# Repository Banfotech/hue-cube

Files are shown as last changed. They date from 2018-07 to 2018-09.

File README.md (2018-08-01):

# Introduction 

The HueCube is a small colorful, programmable cube measuring 46x46x46mm.
You can play around with the example code using the [Arduino IDE](https://www.arduino.cc/), and change it's behavior.
By reading data from the embedded sensors, you can let the colors change by temperature, height, angle, tapping, tilting, dropping or humidity. See the following videos for a few examples:

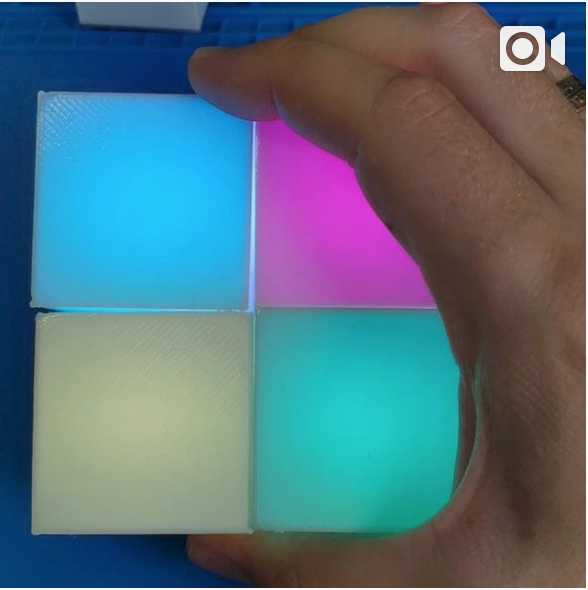
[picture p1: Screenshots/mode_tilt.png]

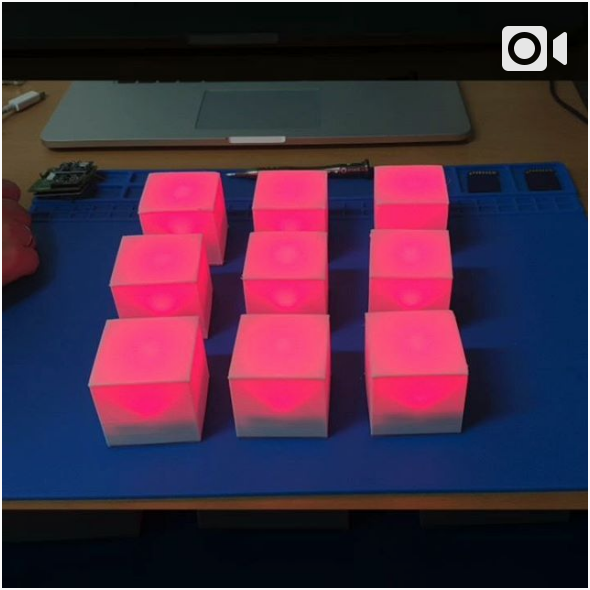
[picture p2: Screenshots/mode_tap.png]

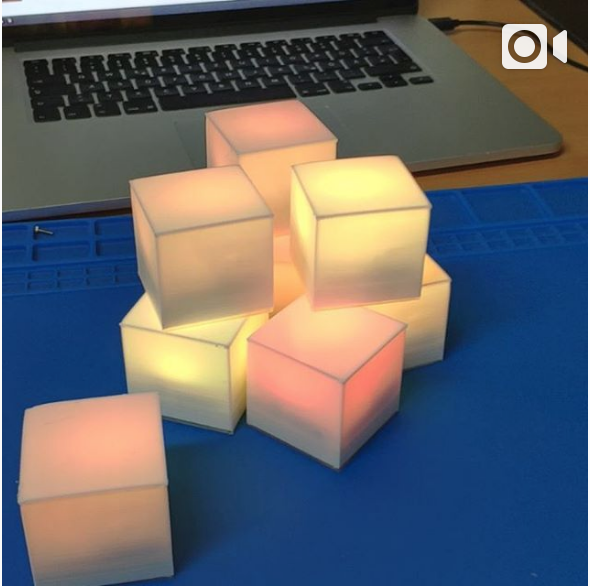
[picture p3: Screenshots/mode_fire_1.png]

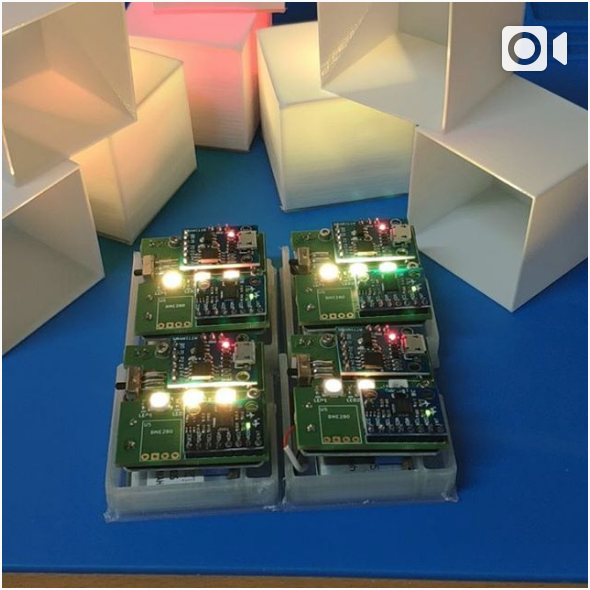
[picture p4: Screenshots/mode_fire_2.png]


## What do you need?

### Soldering
To assemble the board you need to be able to solder SMD components (0603) and a few pins. I am using [this](https://www.aliexpress.com/item/Hot-Sale-220V-110V-60W-Adjustable-Temperature-Electric-Soldering-Iron-Welding-Solder-Station-Heat-Pencil-With/32434361333.html) and [this](https://www.aliexpress.com/item/Free-Shipping-0-3mm-0-4mm-0-5-mm0-6mm-Tin-Lead-Rosin-Core-Solder-Wire/32335236726.html).

### Software
- [Blender3D](https://www.blender.org/), to design the 3d printed case:
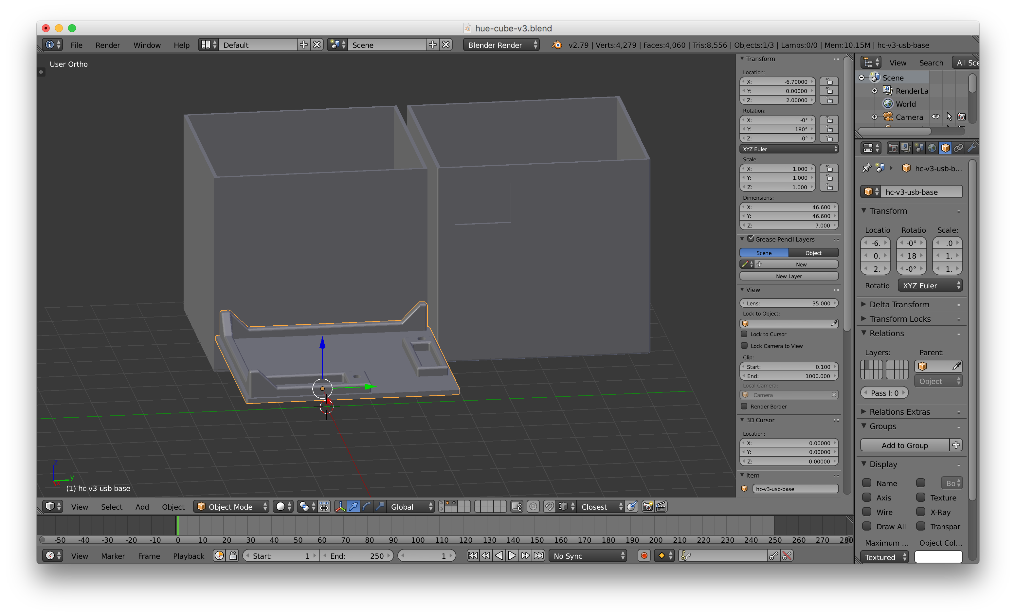
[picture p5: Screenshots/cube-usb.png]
    * USB Powered: <br/>
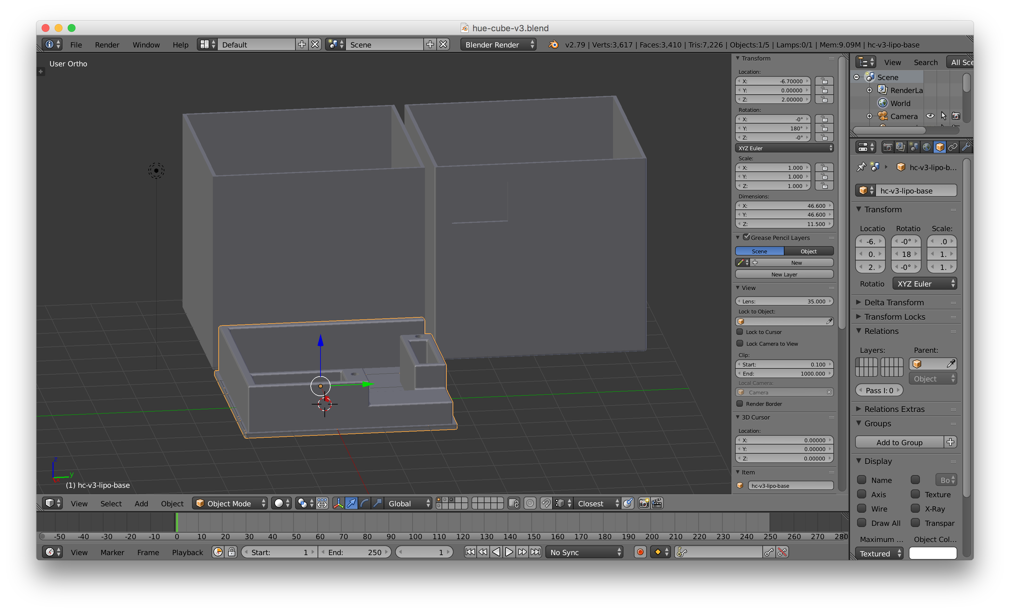
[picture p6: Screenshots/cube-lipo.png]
    * LiPo Powered:<br/>
- [KiCad](http://kicad-pcb.org/), to design the PCB
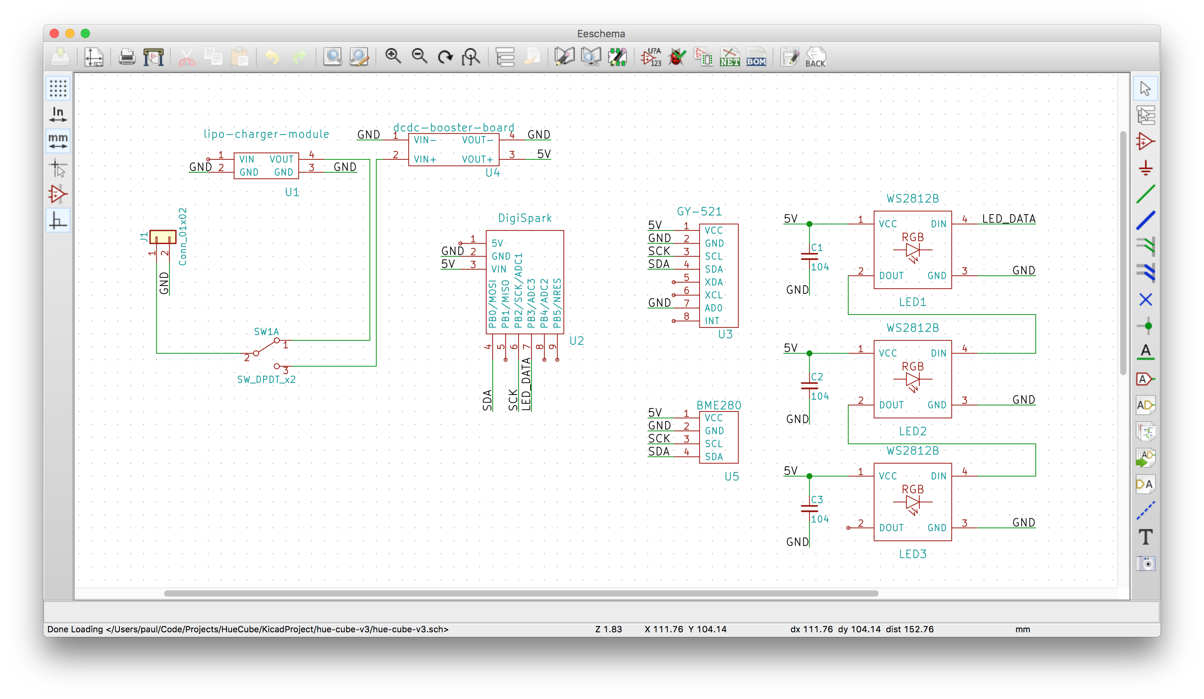
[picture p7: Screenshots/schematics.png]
    * Schematics: <br/>
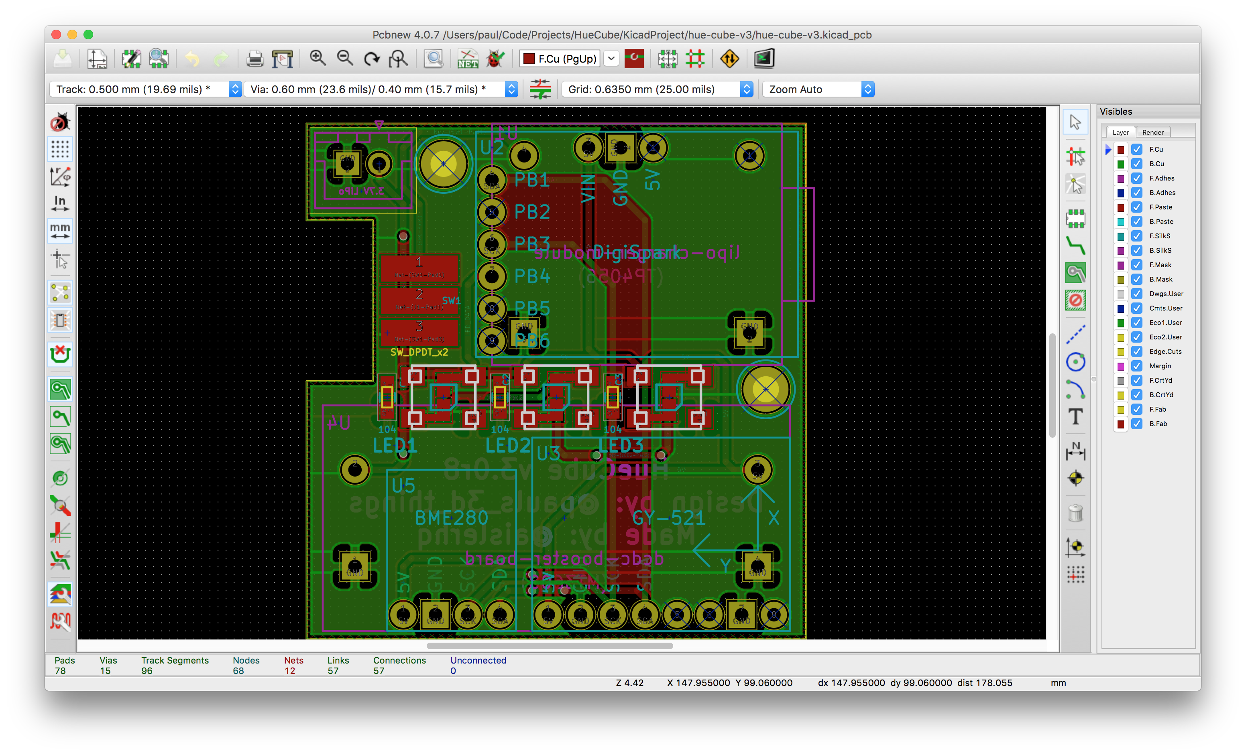
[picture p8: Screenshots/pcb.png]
    * Circuit Board: <br/>
- [Arduino IDE](https://www.arduino.cc/), to write the code and flash the device
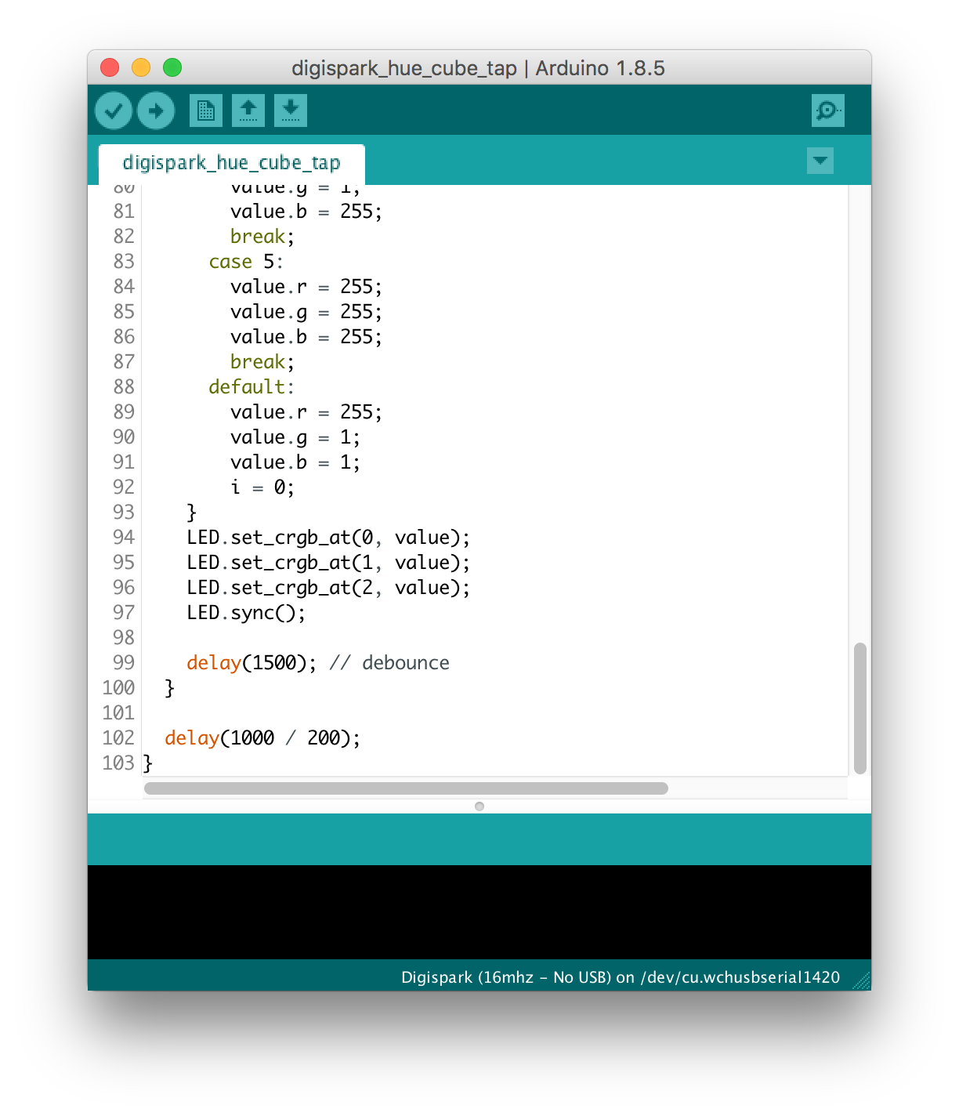
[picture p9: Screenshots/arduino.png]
   * <br/>
   * The [light_ws2812](https://github.com/cpldcpu/light_ws2812) library to control the LEDs. Download the .zip from the `/light_ws2812_Arduino/` folder and place it into `Arduino/libraries/`. I chose this library, due to the small flash size of the attiny85.

### Hardware
The HueCube is made of small, electronic modules that are soldered onto a PCB. You can order the PCB directly from [AISLER](https://aisler.net/p/VAADXKWB), or use the [KiCad](http://kicad-pcb.org/) project files form this repository to modify it.
Currently, there are two design variant.

- USB Powered
    * 3D printed parts: 1x `BlenderModel/hc-v3-usb-base.stl` and  1x `BlenderModel/hc-v3-usb-cube.stl`
    * [1x ATTiny / DigiSpark](https://www.aliexpress.com/item/Attiny85-Digispark-Kickstarter-Development-Board-Module-For-Arduino-Built-in-USB-500ma-5V-Regulator-8k-Flash/32279051124.html)
    * [1x MPU-6050](https://www.aliexpress.com/item/MPU-6050-3-Axis-gyroscope-acce-lerometer-module-3V-5V-compatible-For-Arduino/2035920870.html)
    * [1x ON/OFF Switch](https://www.aliexpress.com/item/Promotion-50-Pcs-SS12D00G3-2-Position-SPDT-1P2T-3-Pin-PCB-Panel-Mini-Vertical-Slide-Switch/32649542037.html) (I know, not the ideal switch, but I had those lying around, so I will be using them)
    * [3x WS2812B](https://www.aliexpress.com/item/100PCS-New-Version-WS2812B-5050-RGB-SMD-WS2811-IC-WS2812-For-Strip-Screen-etc/32776703442.html) you can use them for all sorts of projects ;)
    * [3x 0603 100nF Capacitor](https://www.aliexpress.com/item/MCIGICM-100pcs-0603-smd-capacitor-ceramic-22pf-100nf-1uf-2-2uf-4-7uf-10uf-capacitors-kit/32841971485.html) (or you could search for a kit with multiple values)
- LiPo Powered
    * 3D printer files: 1x `BlenderModel/hc-v3-lipo-base.stl` and 1x `BlenderModel/hc-v3-lipo-cube.stl`
    * [1x TP4056 LiPo Charger](https://www.aliexpress.com/item/5Pcs-Lot-TP4056-Micro-USB-5V-1A-18650-Lithium-Battery-Charger-Board-With-Led-Indicator-Over/32675099957.html) **⚠️make sure to replace the PROG resistor⚠️**. The resistor value depends on your LiPo size. When using a 400mA battery, use [1x 10k Ohm 0603](https://www.aliexpress.com/item/300pcs-0603-SMD-Resistor-1-6-8K-7-5K-8-2K-9-1K-10K-ohm/32308220603.html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), this will give you around ~100mA charging current. (or you could search for a kit with multiple values)
    * [1x MT3608 DC-DC Step Up Converter](https://www.aliexpress.com/item/5pcs-MT3608-DC-DC-Step-Up-Power-Apply-Module-Booster-Power-Module-MAX-output-28V-2A/32517710689.html) **⚠️set this to 5V output before soldering⚠️**

## How to Build?

### Soldering

#### Manually soldering the LEDs
First, solder the WS2812B to the PCB, note the corner with the triangle is GND, so this needs to be aligned to the bottom right pad. See the video for detais:

*Video:*

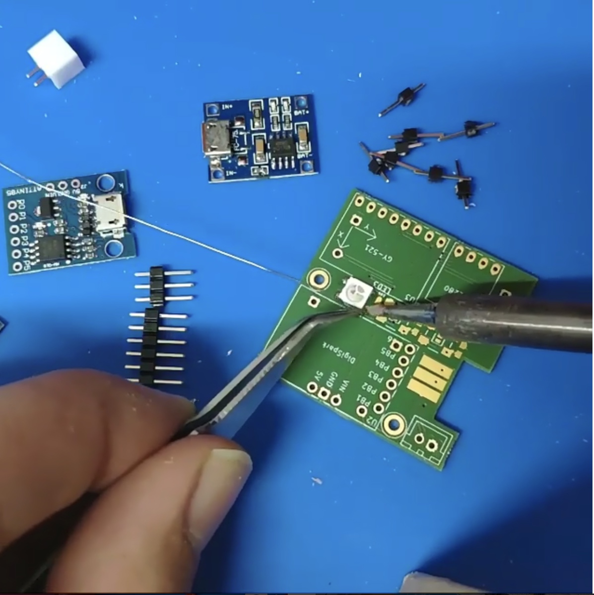
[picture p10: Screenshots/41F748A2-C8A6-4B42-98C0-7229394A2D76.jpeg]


#### SMD soldering the LEDs
If you have a hot airstation and liquid solder, it is a lot easier to solder the SMD components:

*Video:*

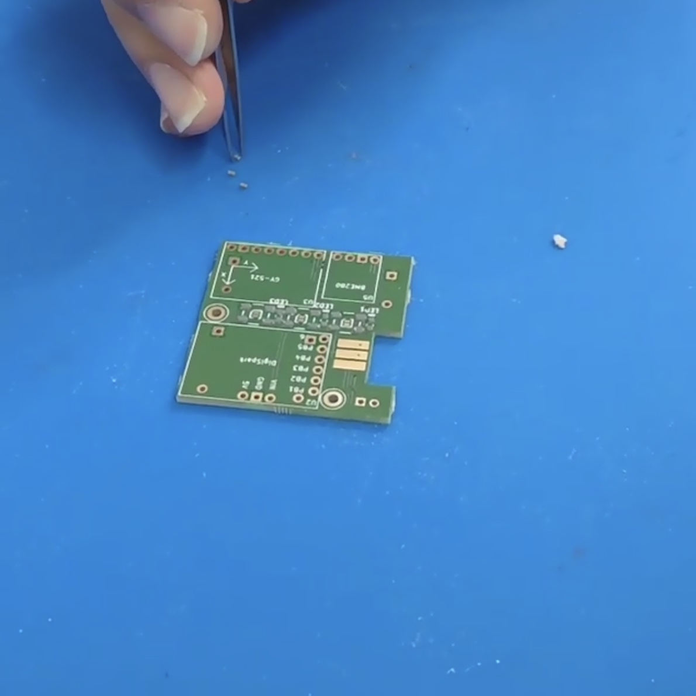
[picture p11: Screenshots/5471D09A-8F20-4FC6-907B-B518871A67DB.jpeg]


#### Pins
After the LEDs and capacitors, you will need to solder the pins. 
**Important:** You need to know in advance if you want to build the LiPo version or not, otherwise you will not be able to add the respective pins for the DCDC booster and the LiPo charger module.

*Video:*

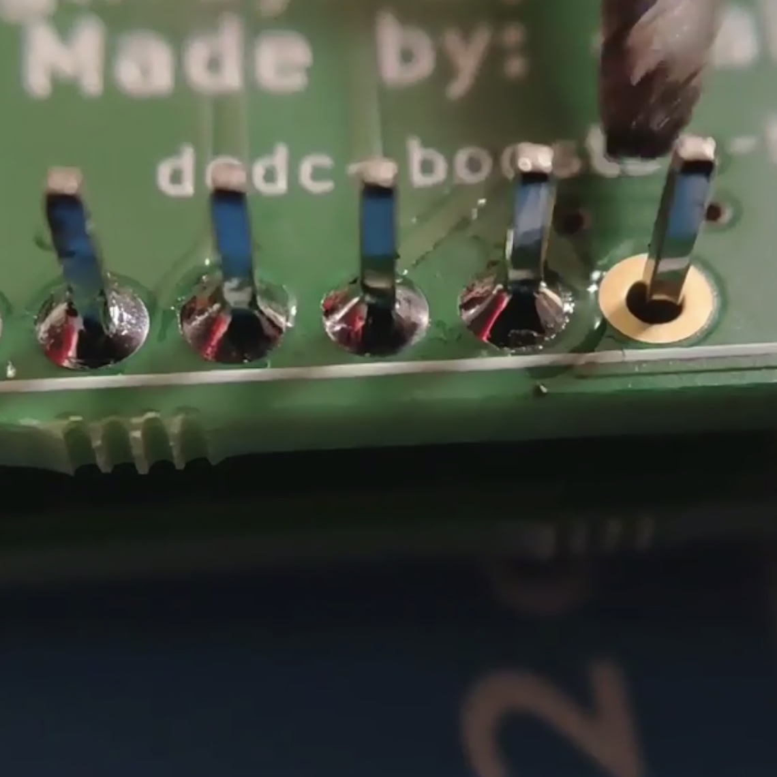
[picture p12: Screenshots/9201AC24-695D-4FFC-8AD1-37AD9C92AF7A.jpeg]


#### Sensor + DigiSpark (USB Version)
The USB version only requires soldering the top parts

*Video:*

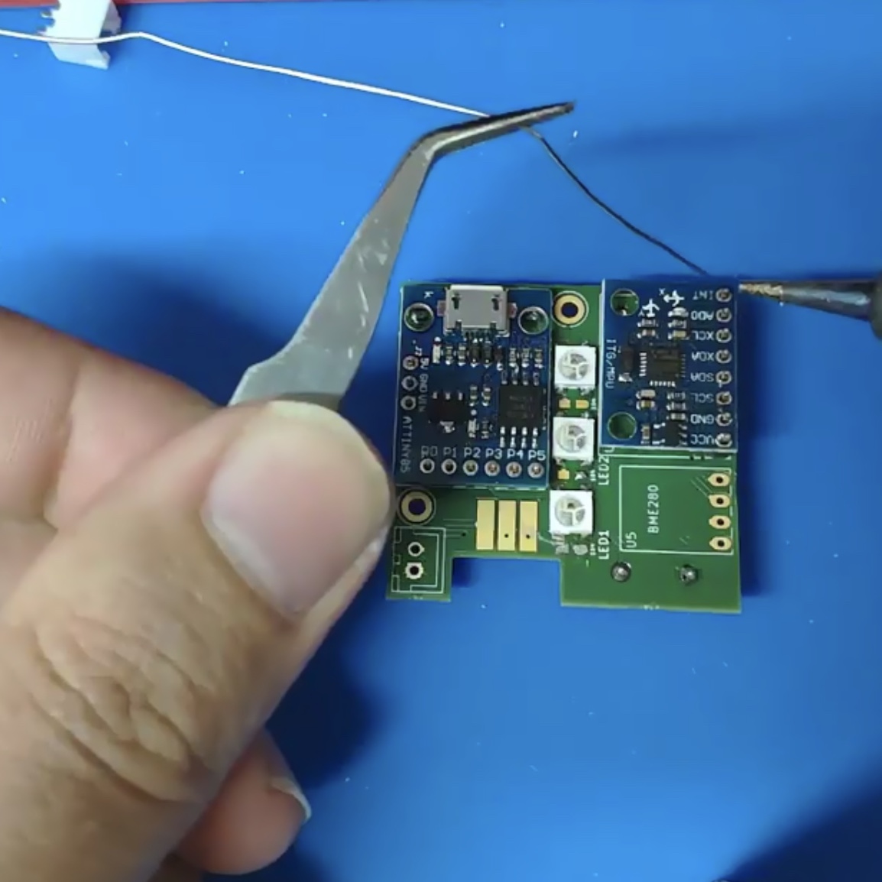
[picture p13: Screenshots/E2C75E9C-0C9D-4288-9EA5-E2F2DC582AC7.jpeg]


#### DCDC Booster + LiPo Charger
Note, make sure you have the pins in place. Set the DCDC booster to 5V **before soldering** and **replace the PROG resistor** with a 10k resistor to make sure you only have small charging current of about 120mA.

*Video:*

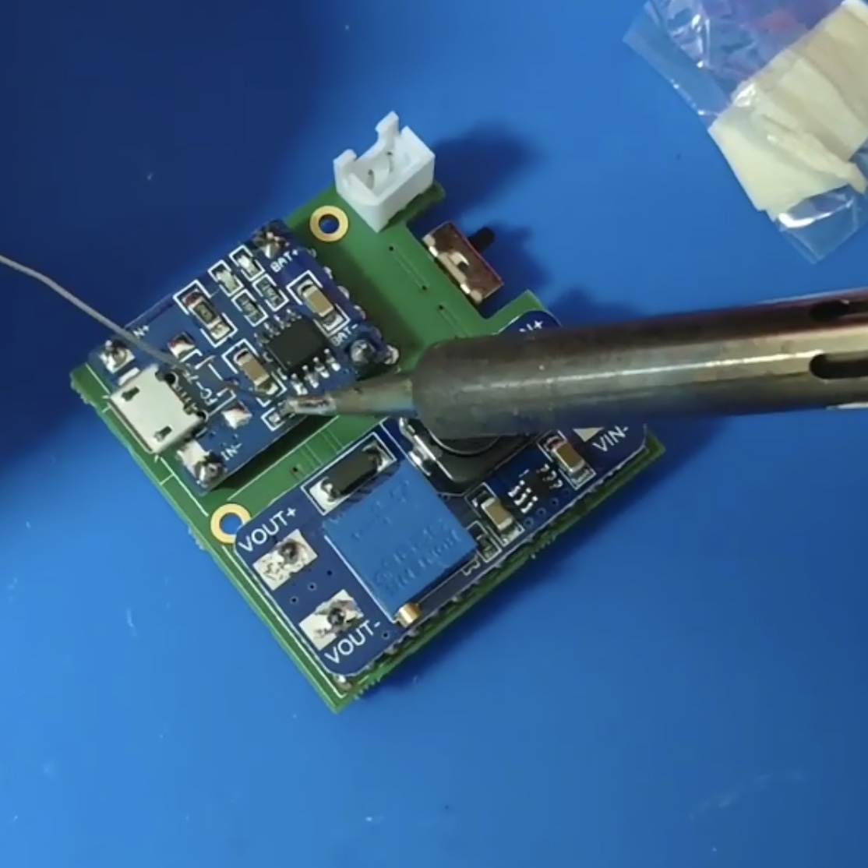
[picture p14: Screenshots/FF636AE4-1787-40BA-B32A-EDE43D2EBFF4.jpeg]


#### Switch and Battery Connector
I think you will figure these out on your own. The square pin hole (PCB rev.8) is GND (black cable), the other 3.7V (red cable). Solder the connector facing to the bottom, i.e. not on the side of the LEDs.
The switch selects whether the LiPo charger is connected (=OFF or Charging) or the DCDC booster is conencted (=ON). **Never connect the USB while the huecube is on**. I have done it and nothing happened. But it is not designed to work this way.

### 3D Printing
TODO 😅

### Programming
TODO

## License

See the respective subfolders for their LICENSE.

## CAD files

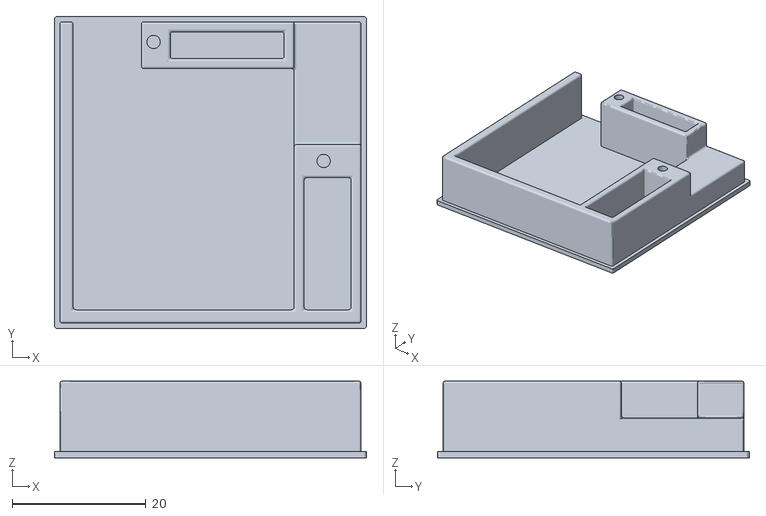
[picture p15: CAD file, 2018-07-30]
BlenderModel/hc-v3-lipo-base.stl
46.6 x 46.6 x 11.5

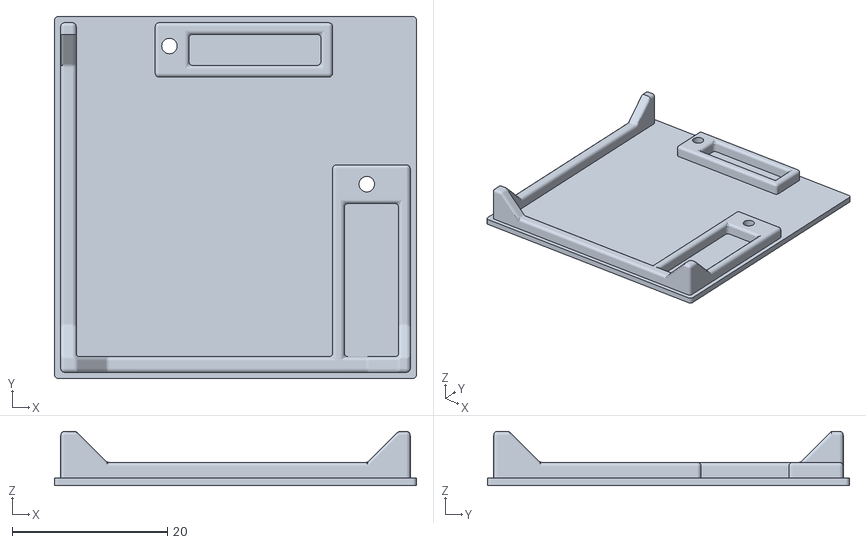
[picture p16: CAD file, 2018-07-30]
BlenderModel/hc-v3-usb-base.stl
46.6 x 46.6 x 7.00

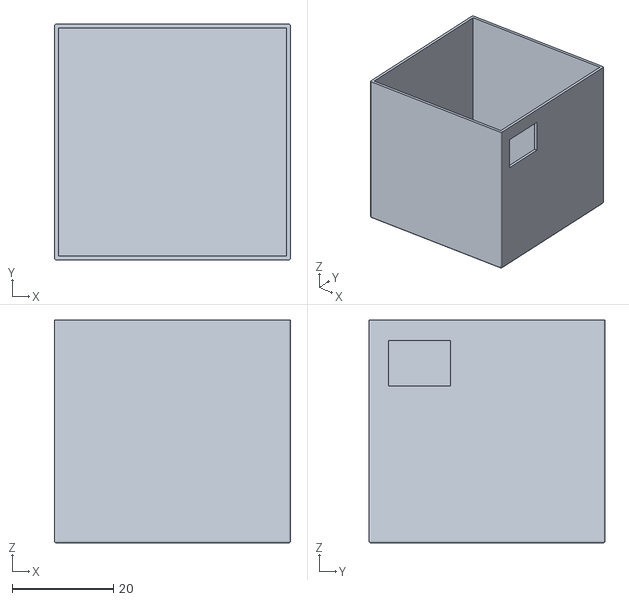
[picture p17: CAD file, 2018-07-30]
BlenderModel/hc-v3-usb-cube.stl
46.6 x 46.6 x 44.0

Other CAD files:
BlenderModel/hc-v3-lipo-cube.stl
BlenderModel/hue-cube-v3.blend

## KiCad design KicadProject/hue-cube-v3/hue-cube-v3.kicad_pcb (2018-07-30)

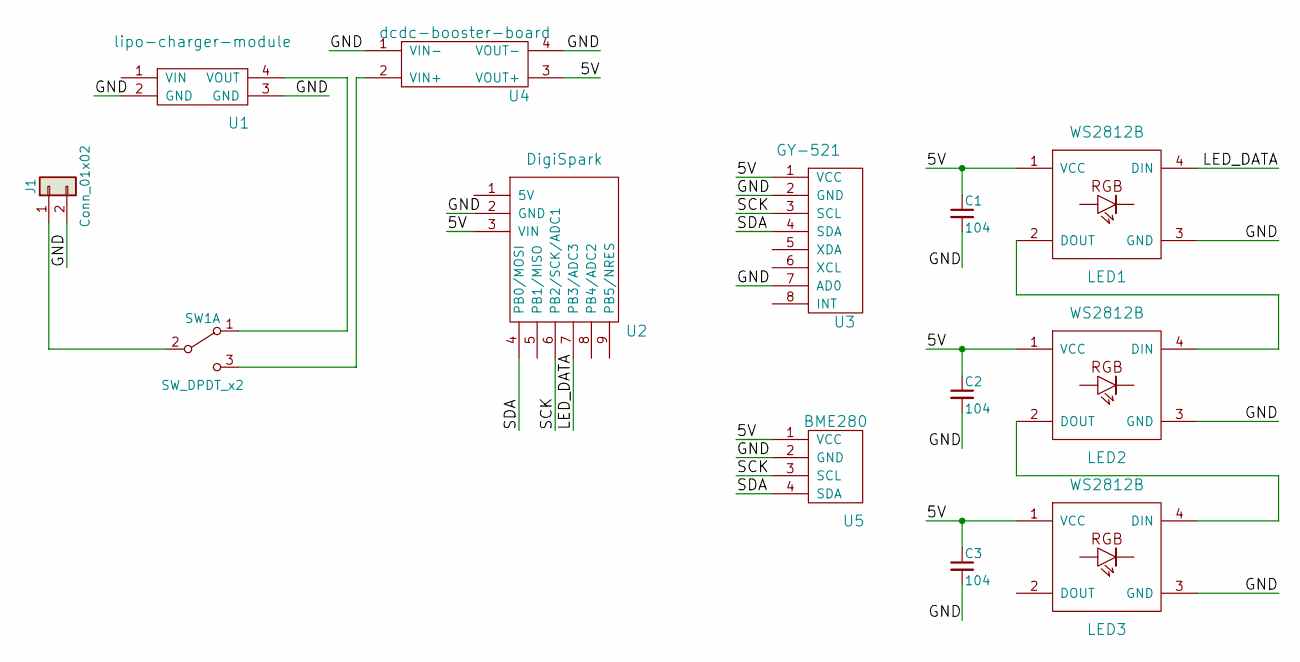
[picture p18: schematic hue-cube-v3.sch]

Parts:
C1, C2, C3: 104; C_0603_HandSoldering_narrow
J1: Conn_01x02; JST_XH_B02B-XH-A_02x2.50mm_Straight
LED1, LED2, LED3: WS2812B; WS2812B_data-bridgeable
SW1: SW_DPDT_x2; flat-switch-2.54mm-smd
U1: lipo-charger-module; lipo-charger-board
U2: DigiSpark
U3: GY-521
U4: dcdc-booster-board
U5: BME280

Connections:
/5V: C1.1, C2.1, C3.1, LED1.1 (VCC), LED2.1 (VCC), LED3.1 (VCC), U2.3 (VIN), U3.1 (VCC), U4.3 (VOUT+), U5.1 (VCC)
/GND: C1.2, C2.2, C3.2, J1.2, LED1.3 (GND), LED2.3 (GND), LED3.3 (GND), U1.2 (GND), U1.3 (GND), U2.2 (GND), U3.2 (GND), U3.7 (AD0), U4.1 (VIN-), U4.4 (VOUT-), U5.2 (GND)
/LED_DATA: LED1.4 (DIN), U2.7 (PB3/ADC3)
/SCK: U2.6 (PB2/SCK/ADC1), U3.3 (SCL), U5.3 (SCL)
/SDA: U2.4 (PB0/MOSI), U3.4 (SDA), U5.4 (SDA)
unnamed: J1.1, SW1.2 (B)
unnamed: LED1.2 (DOUT), LED2.4 (DIN)
unnamed: LED2.2 (DOUT), LED3.4 (DIN)
unnamed: SW1.1 (A), U1.4 (VOUT)
unnamed: SW1.3 (C), U4.2 (VIN+)

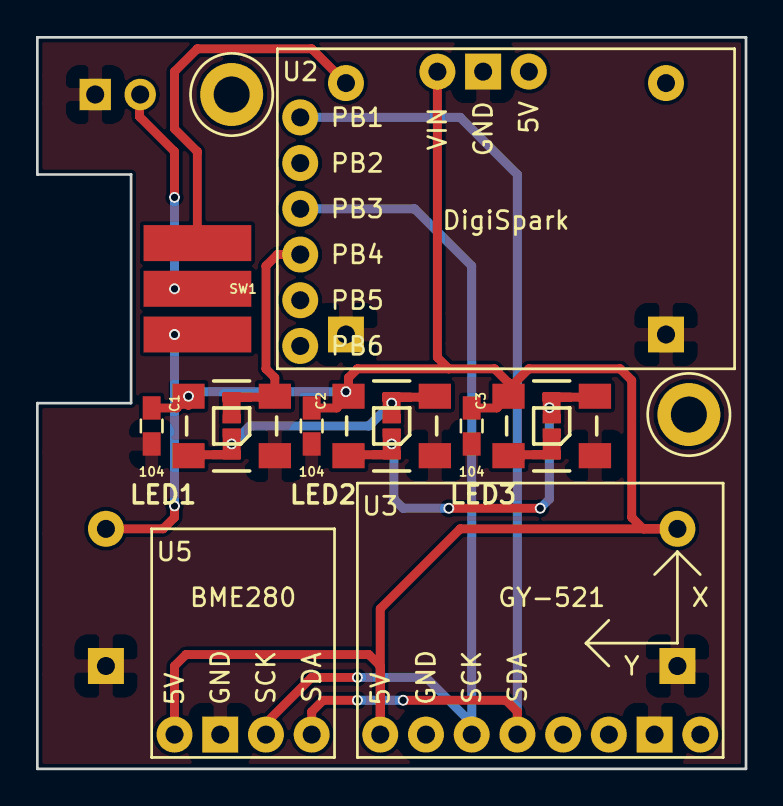
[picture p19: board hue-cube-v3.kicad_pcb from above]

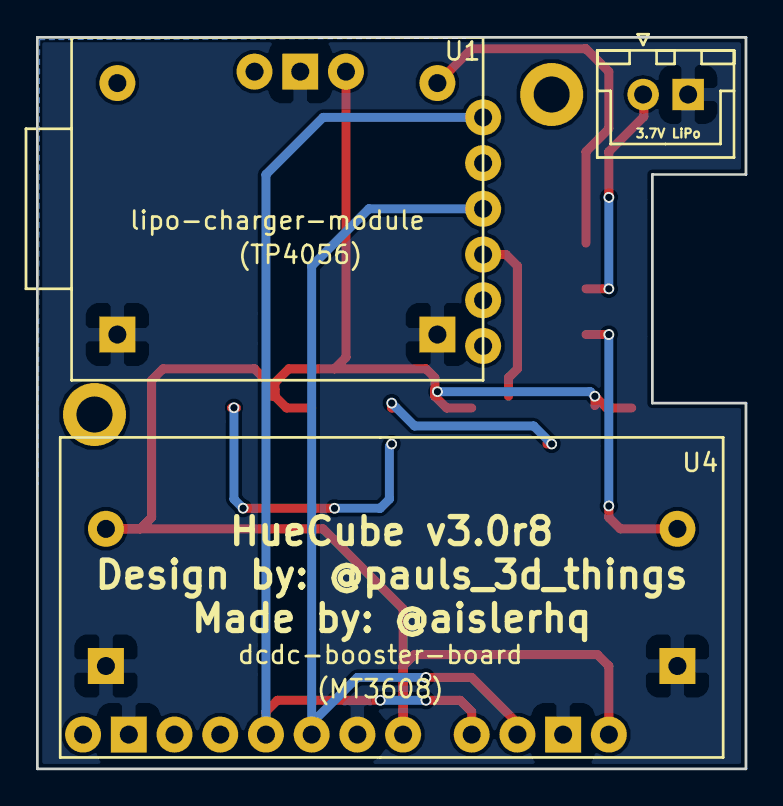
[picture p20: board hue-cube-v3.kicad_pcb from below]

Board: 2 copper layers, 39.4 x 40.6 mm, 13 parts (3 on the bottom side), 10 nets.

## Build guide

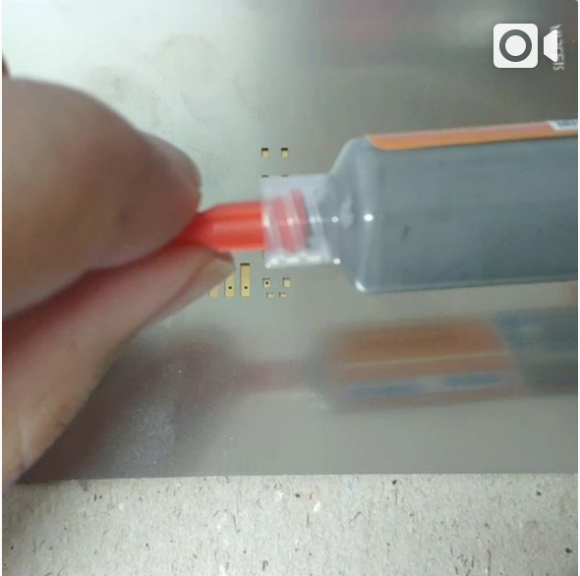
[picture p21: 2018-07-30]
Screenshots/smd_soldering_1.png

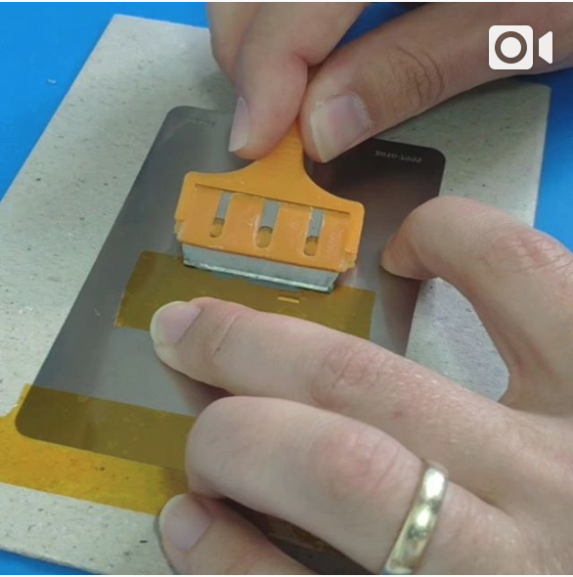
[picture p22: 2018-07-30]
Screenshots/smd_soldering_2.png

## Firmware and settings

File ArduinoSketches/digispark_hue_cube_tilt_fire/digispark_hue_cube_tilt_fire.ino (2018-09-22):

// sources: https://playground.arduino.cc/Main/MPU-6050
#include <Wire.h>
#define USE_HSV // enable hsv mode
#include <WS2812.h>

#define MAX_BRIGHTNESS 255
#define MPUADDR 0x68

#define CHANGE_FACTOR 2400
#define DEBOUNCE_DELAY 66
#define NUM_MODES 2

WS2812 LED(3);
uint8_t mode = 0;

int16_t acX, acY, acZ, GyX, GyY, GyZ; // Temp
int16_t acXf, acYf, acZf; // temp

// HUE MODE
int16_t hue = 0, sat = 255, val = 64;
float change;

// FIRE MODE
cRGB led1;
cRGB led2;
cRGB led3;
int16_t s; // anim speed
int16_t r; // amount of red
float f, rf, gf;

void flicker(cRGB *rgb) {
  f = random(64) - 20; // colors get brighter
  rf = random(16) - 8;
  gf = random(16) - 6; // yellows are more often
  rgb->r += rf + f;
  rgb->g += gf + f;

  // darker colors have more reds
  if (rgb->r <= r) {
    rgb->g = rgb->g - rgb->r / 2;
  }

  // bright colors flicker to darker colors
  rgb->r = rgb->r >= 254 ? 10 : (rgb->r <= 0 ? 0 : rgb->r);
  rgb->g = rgb->g >= 254 ? 10 : (rgb->g <= 0 ? 0 : rgb->g);

  // there is never a green flame (not even slightly)
  rgb->g = rgb->g > rgb->r ? rgb->r : rgb->g;
  // there is never a red flame (but a little is ok)
  rgb->r = rgb->r - 100 >= rgb->g ? rgb->r - 50 : rgb->r;

}
void setup() {
  Wire.begin();
  Wire.beginTransmission(MPUADDR);
  Wire.write(0x6B);  // PWR_MGMT_1 register
  Wire.write(0);     // set to zero (wakes up the MPU-6050)
  Wire.endTransmission(true);
  LED.setOutput(3); // Digital Pin 9

  // fire mode
  s = 33;
  r = 120;
}

void loop() {
  Wire.beginTransmission(MPUADDR);
  Wire.write(0x3B);  // starting with register 0x3B (ACCEL_XOUT_H)
  Wire.endTransmission(false);
  Wire.requestFrom(MPUADDR, 14); // request a total of 14 registers
  acX = (Wire.read() << 8 | Wire.read()); // 0x3B (ACCEL_XOUT_H) & 0x3C (ACCEL_XOUT_L)
  acY = (Wire.read() << 8 | Wire.read()); // 0x3D (ACCEL_YOUT_H) & 0x3E (ACCEL_YOUT_L)
  acZ = (Wire.read() << 8 | Wire.read()); // 0x3F (ACCEL_ZOUT_H) & 0x40 (ACCEL_ZOUT_L)
  // Temp = Wire.read() << 8 | Wire.read(); // 0x41 (TEMP_OUT_H) & 0x42 (TEMP_OUT_L)
  // GyX = Wire.read() << 8 | Wire.read(); // 0x43 (GYRO_XOUT_H) & 0x44 (GYRO_XOUT_L)
  // GyY = Wire.read() << 8 | Wire.read(); // 0x45 (GYRO_YOUT_H) & 0x46 (GYRO_YOUT_L)
  // GyZ = Wire.read() << 8 | Wire.read(); // 0x47 (GYRO_ZOUT_H) & 0x48 (GYRO_ZOUT_L)

  // low pass filter to remove noise:
  acXf = acXf * 0.7 + 0.3 * (acX); // 0x3B (ACCEL_XOUT_H) & 0x3C (ACCEL_XOUT_L)
  acYf = acYf * 0.7 + 0.3 * (acY); // 0x3D (ACCEL_YOUT_H) & 0x3E (ACCEL_YOUT_L)
  acZf = acZf * 0.7 + 0.3 * (acZ); // 0x3F (ACCEL_ZOUT_H) & 0x40 (ACCEL_ZOUT_L)


  if ( abs(acX - acXf) > 8000 || abs(acY - acYf) > 8000 || abs(acZ - acZf) > 8000) {
    mode = (mode + 1) % NUM_MODES;
    led1.SetHSV(1, 1, 1);
    LED.set_crgb_at(0, led1);
    LED.set_crgb_at(1, led1);
    LED.set_crgb_at(2, led1);
    LED.sync();
    delay(3000);
  }

  switch (mode) {
    case 1: // fire

      if (abs(acXf) > CHANGE_FACTOR) {
        r = r + (acXf * (1.0 / CHANGE_FACTOR));
        r = r >= 180 ? 180 : r;
        r = r <= 0 ? 0 : r;
        delay(DEBOUNCE_DELAY); // debounce
      }

      if (abs(acYf) > CHANGE_FACTOR) {
        s = s + (acYf * (1.0 / CHANGE_FACTOR));
        s = s >= 1000 ? 1000 : s;
        s = s <= 10 ? 10 : s;
        delay(DEBOUNCE_DELAY); // debounce
      }

      delay(1000 / s);

      switch (random(0, 3)) {
        case 0:
          flicker(&led1);
          break;
        case 1:
          flicker(&led2);
          break;
        case 2:
          flicker(&led3);
          break;
      }

      LED.set_crgb_at(0, led1);
      LED.set_crgb_at(1, led2);
      LED.set_crgb_at(2, led3);
      LED.sync();
      break;
    case 0:
    default:
      if (abs(acXf) > CHANGE_FACTOR) {
        hue = hue + (acXf * (1.0 / CHANGE_FACTOR));
        hue = hue >= 360 ? 1 : hue;
        hue = hue <= 0 ? 359 : hue;
        delay(DEBOUNCE_DELAY); // debounce
      }

      if (abs(acYf) > CHANGE_FACTOR) {
        val = val + (acYf * (1.0 / CHANGE_FACTOR));
        val = val >= MAX_BRIGHTNESS ? MAX_BRIGHTNESS : val;
        val = val <= 5 ? 5 : val;
        delay(DEBOUNCE_DELAY); // debounce
      }
      led1.SetHSV(hue, sat, val);
      LED.set_crgb_at(0, led1);
      LED.set_crgb_at(1, led1);
      LED.set_crgb_at(2, led1);
      LED.sync();
  }


  delay(1000 / 200);
}

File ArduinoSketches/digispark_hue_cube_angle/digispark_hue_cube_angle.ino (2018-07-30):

// sources: https://playground.arduino.cc/Main/MPU-6050
#include <Wire.h>
#include <WS2812.h>

WS2812 LED(3);
cRGB value;
#define MAX_BRIGHTNESS 128
#define MPUADDR 0x68
int16_t AcX, AcY, AcZ, Tmp, GyX, GyY, GyZ;

void setup() {
  delay(200);
  digitalWrite(1, HIGH);
  delay(200);
  digitalWrite(1, LOW);
  delay(200);
  digitalWrite(1, HIGH);
  delay(200);
  digitalWrite(1, LOW);
  delay(200);
  digitalWrite(1, HIGH);
  delay(200);
  digitalWrite(1, LOW);

  Wire.begin();
  Wire.beginTransmission(MPUADDR);
  Wire.write(0x6B);  // PWR_MGMT_1 register
  Wire.write(0);     // set to zero (wakes up the MPU-6050)
  Wire.endTransmission(true);
  LED.setOutput(3); // Digital Pin 9
}

void loop() {
  Wire.beginTransmission(MPUADDR);
  Wire.write(0x3B);  // starting with register 0x3B (ACCEL_XOUT_H)
  Wire.endTransmission(false);
  Wire.requestFrom(MPUADDR, 14); // request a total of 14 registers
  
  // low pass filter to remove noise:
  AcX = AcX * 0.95 + 0.05 * (Wire.read() << 8 | Wire.read()); // 0x3B (ACCEL_XOUT_H) & 0x3C (ACCEL_XOUT_L)
  AcY = AcY * 0.95 + 0.05 * (Wire.read() << 8 | Wire.read()); // 0x3D (ACCEL_YOUT_H) & 0x3E (ACCEL_YOUT_L)
  AcZ = AcZ * 0.95 + 0.05 * (Wire.read() << 8 | Wire.read()); // 0x3F (ACCEL_ZOUT_H) & 0x40 (ACCEL_ZOUT_L)
  Tmp = Wire.read() << 8 | Wire.read(); // 0x41 (TEMP_OUT_H) & 0x42 (TEMP_OUT_L)
  GyX = Wire.read() << 8 | Wire.read(); // 0x43 (GYRO_XOUT_H) & 0x44 (GYRO_XOUT_L)
  GyY = Wire.read() << 8 | Wire.read(); // 0x45 (GYRO_YOUT_H) & 0x46 (GYRO_YOUT_L)
  GyZ = Wire.read() << 8 | Wire.read(); // 0x47 (GYRO_ZOUT_H) & 0x48 (GYRO_ZOUT_L)

  // Tmp/340.00+36.53  //equation for temperature in degrees C from datasheet

  if (AcX > 1000) {
    digitalWrite(1, HIGH);
  } else {
    digitalWrite(1, LOW);
  }

  value.r = abs(AcX) >= 32768 / 2 ? MAX_BRIGHTNESS : map(abs(AcX), 0, 32768 / 2, 0, MAX_BRIGHTNESS);
  value.g = abs(AcY) >= 32768 / 2 ? MAX_BRIGHTNESS : map(abs(AcY), 0, 32768 / 2, 0, MAX_BRIGHTNESS);
  value.b = abs(AcZ) >= 32768 / 2 ? MAX_BRIGHTNESS : map(abs(AcZ), 0, 32768 / 2, 0, MAX_BRIGHTNESS);

  LED.set_crgb_at(0, value);
  LED.set_crgb_at(1, value);
  LED.set_crgb_at(2, value);
  LED.sync();

  delay(1000 / 100);
}

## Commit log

2018-08-01 Add info about LEDs and DCDC converter
2018-09-22 Add switchable tilte+fire mode
